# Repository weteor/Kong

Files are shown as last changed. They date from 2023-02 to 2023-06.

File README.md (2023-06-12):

### Kong

48 key orthogonal keyboard with offset bottom row

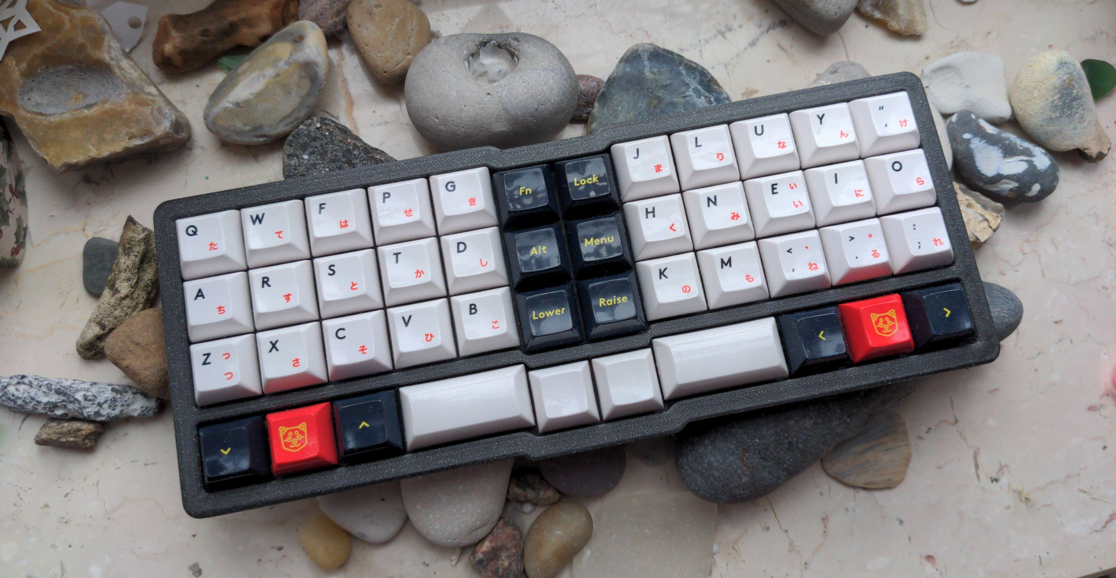
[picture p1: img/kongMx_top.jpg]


## Features

- seperate pcbs/cases for choc v1 and mx switches.
- Hotswap sockets
- onboard rp2040
- production files for pcba
- case files are supplied (stl, dxf, as well as the freecad files)
- QMK with vial support
- completely open source, permissive license ([CERN-OHL-P](https://cern-ohl.web.cern.ch/home))
- bottom rows supported:
  - 6x1u (MX)
  - 3x1u - 2u (MX and Choc)
  - 2x1u - 3u (MX)

## Want one?

All production files you need to build your own board can be found here: [choc](./prod/choc) / [mx](./prod/mx).

There are also production files with both pcbs combined to save on the assembly costs: [combined](./prod/combined)

## Case

#### Open bottom

The case is split in two parts connected by cylindrical 3mm diameter magnets. Two length are needed, 1.7mm and 3mm. The 3x3mm Magnets go into the shallow holes, so they poke out of the case. The 3x1.7mm magnets are pressed into the deeper holes. The longer magnet acting as a pin increasing stability and keeping the top part in place.

The bottom case is open by design and ends at a bit under the hotswap sockets. It's meant to be used with self adhesive neopren sheets (2-3mm thick), which are cut to be the same size as the pcb and then glued on top of the underside of the pcb.

#### Gasket mount

An alternative gasket mount case with a 4 degree tilt is also available for the MX version. 4mm x 3mm thick strips of foam is used to isolate the plate from PCB. Felt or other soft material similar in thickness can be used. M2 x 6mm flat head screws are used to fasten the case together.

#### Files

- [CAD files](./case)
- [stl (MX)](./prod/mx/case)
- [stl (choc)](./prod/choc/case)

## Parts

Parts needed beside the assembled pcbs:

- 48 hotswap sockets ( mx or choc)
- 48 of your favourite switches (mx or choc)
- (Choc only) 1x 1.6mm mid-mount 16-pin USB-C connector. I've omitted this from assembly to avoid needing the higher tier assembly. Those connectors can easily be found on Aliexpress, Mouse, Digikey etc. and are quite easy to handsolder

## Firmware
firmware configs for qmk and vial can be found in the respective firmware folders: [choc](./firmware/kong) / [mx](./firmware/kongmx).

The first time the pcb is plugged in, the bootloader will provide a drive to upload the firmware file.
You may either build the firmware yourself or use the provided vial firmware files [here](./firmware/uf2). You can use VIAL ([download](https://get.vial.today/) to program your board after that, without need to build a new firmware.

## The rest

Everything in this repository is free to use however you might see fit. If you want to support me and my projects, please consider linking back to this repository if you build/change/use anything.

If you would like to send me a tip, you could do it [here](https://ko-fi.com/weteor) (Please don't feel like you have to).

## More pictures

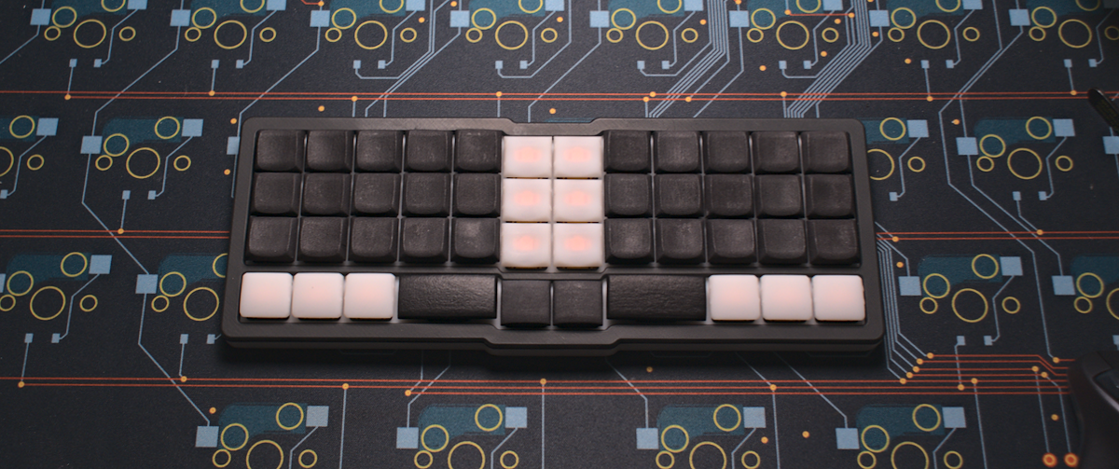
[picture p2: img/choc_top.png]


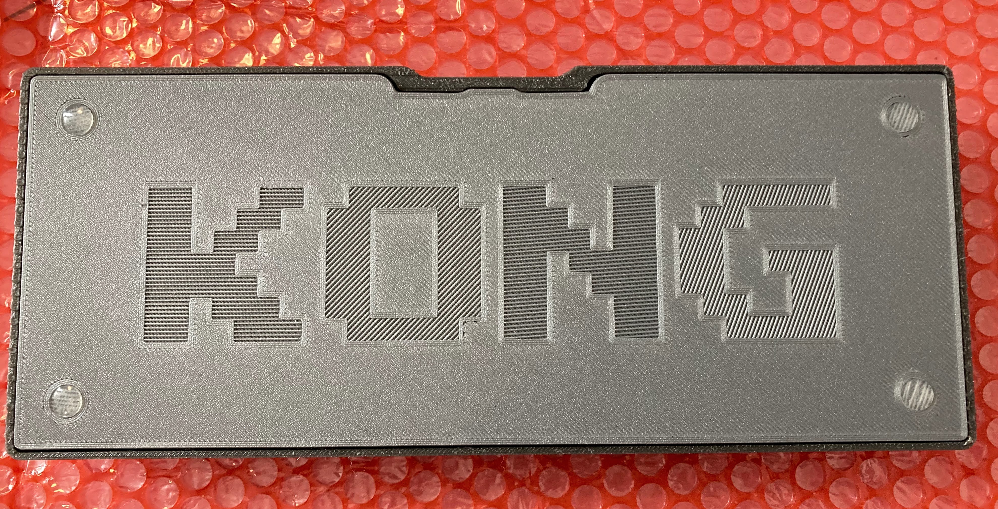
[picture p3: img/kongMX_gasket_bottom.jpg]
bottom


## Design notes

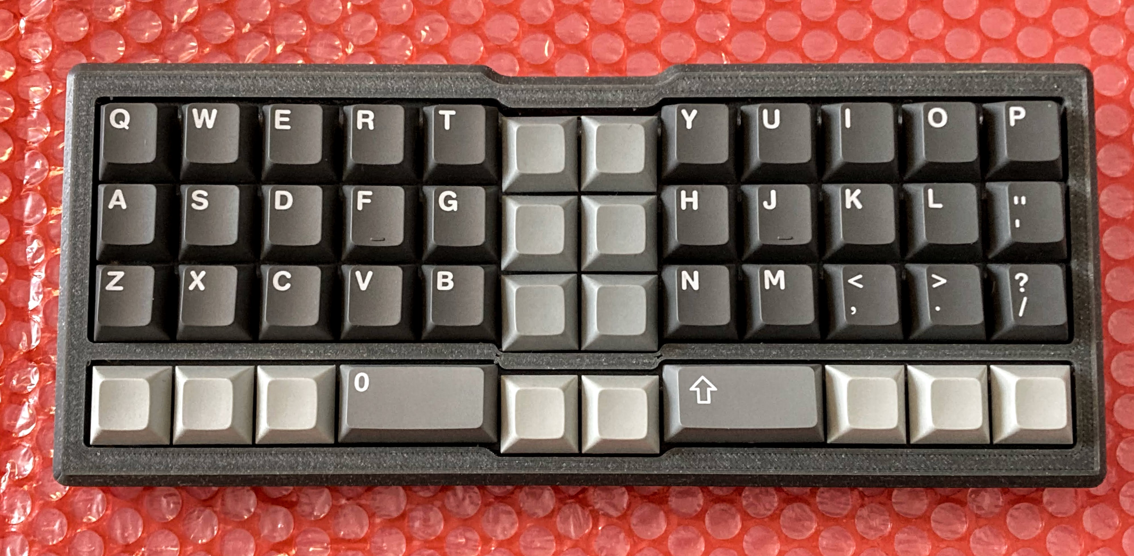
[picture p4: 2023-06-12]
img/kongMX_gasket_top.jpg

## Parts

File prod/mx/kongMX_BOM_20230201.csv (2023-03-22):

Comment | Designator | Footprint | LCSC
1uF | C500,C501,C503,C505 | Capacitor_SMD:C_0402_1005Metric | C52923
100nF | C502,C504,C506,C507,C508,C509,C512,C513 | Capacitor_SMD:C_0402_1005Metric | C1525
27pF | C510,C511 | Capacitor_SMD:C_0402_1005Metric | C1557
D | D500,D501,D502,D503,D504,D505,D506,D507,D508,D509,D510,D511,D512,D513,D514,D515,D516,D517,D518,D519,D520,D521,D522,D523,D524,D525,D526,D527,D528,D529,D530,D531,D532,D533,D534,D535,D536,D537,D538,D539,D540,D541,D542,D543,D544,D545,D546,D547 | weteor:D_SOD-123 | C81598
USB_C_Receptacle_USB2.0 | J500 | weteor:USB-C-31-M-12 | C165948
5.1k | R500,R501 | Resistor_SMD:R_0402_1005Metric | C25905
27R | R502,R503 | Resistor_SMD:R_0402_1005Metric | C100353
1k | R504,R505,R506 | Resistor_SMD:R_0402_1005Metric | C11702
10k | R507 | Resistor_SMD:R_0402_1005Metric | C25744
XC6206PxxxMR | U500 | Package_TO_SOT_SMD:SOT-23 | C5446
USBLC6-2SC6 | U501 | Package_TO_SOT_SMD:SOT-23-6 | C2827654
W25Q128JVS | U502 | Package_SO:SOIC-8_5.23x5.23mm_P1.27mm | C97521
RP2040 | U503 | RP2040_minimal:RP2040-QFN-56 | C2040
Crystal_GND24_Small | Y500 | Crystal:Crystal_SMD_2520-4Pin_2.5x2.0mm | C284156

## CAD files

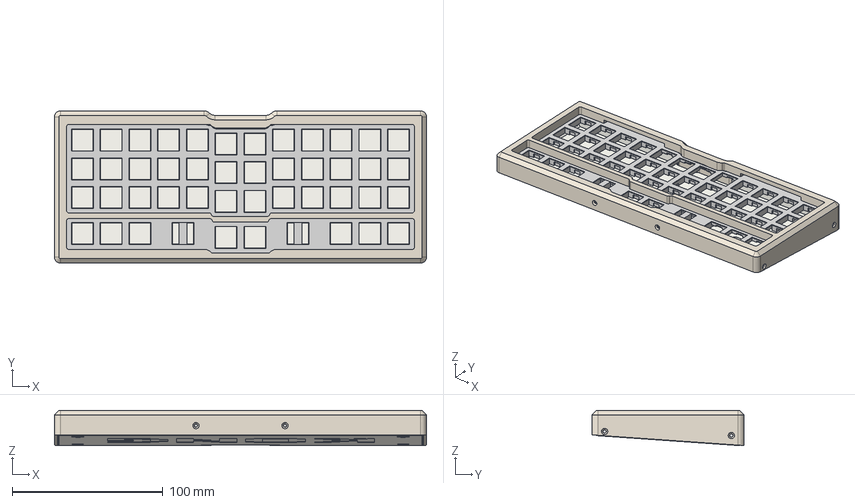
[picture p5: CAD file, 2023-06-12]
case/case_KongMX_gasket.step
246.6 x 101.0 x 23.4 mm
top
bottom
plate 1u
plate 2u

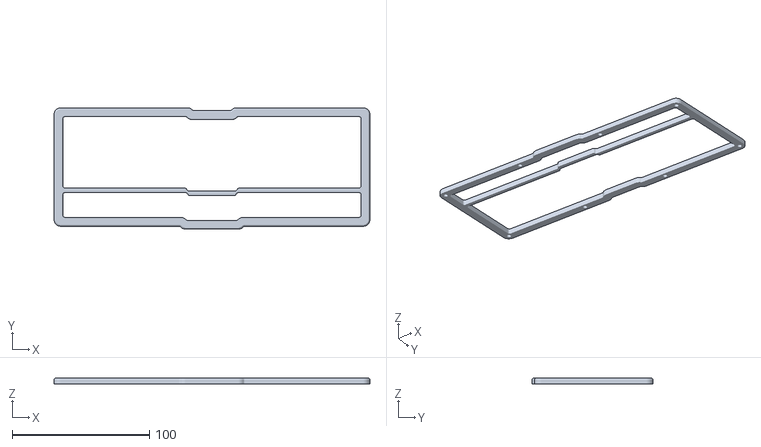
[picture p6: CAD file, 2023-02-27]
prod/choc/case/case_top.stl
230.0 x 88.4 x 4.50

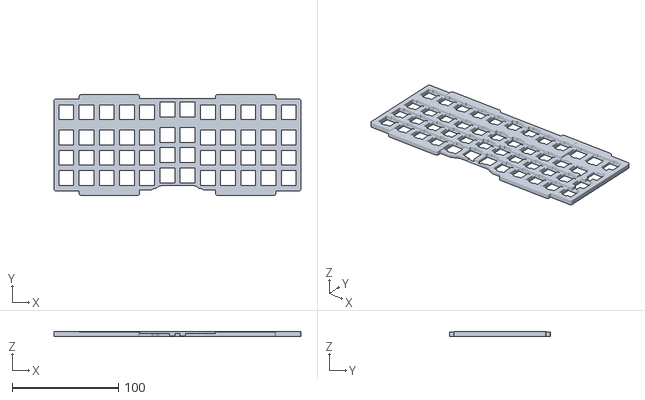
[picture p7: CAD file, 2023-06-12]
prod/mx/case/kongMX_gasket_plate_1u.stl
232.6 x 95.0 x 4.75

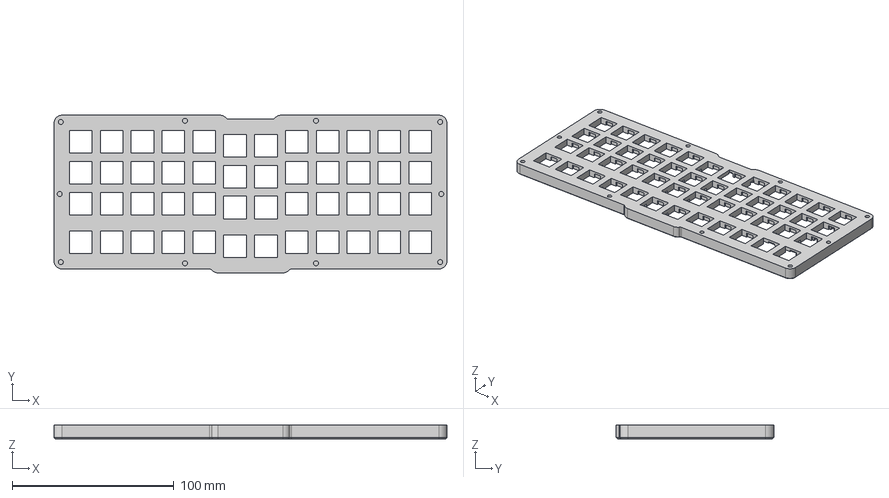
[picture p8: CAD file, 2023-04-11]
case/case_kongMX-Bottom-1u.step
242.6 x 97.3 x 8.35 mm

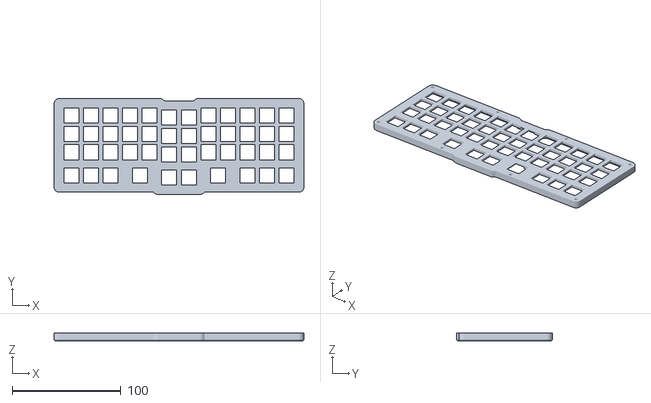
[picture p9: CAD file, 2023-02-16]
prod/choc/case/case_bottom.stl
230.0 x 88.4 x 7.05

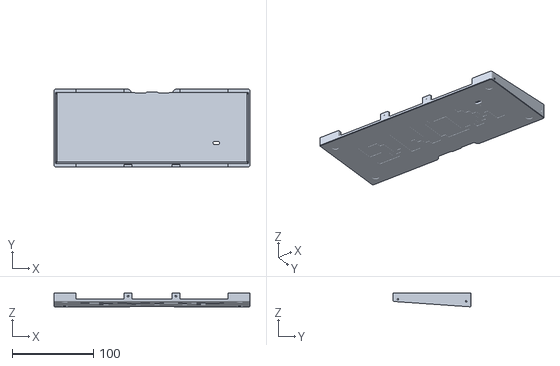
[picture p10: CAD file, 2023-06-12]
prod/mx/case/kongMX_gasket_bottom.stl
241.6 x 96.0 x 16.9

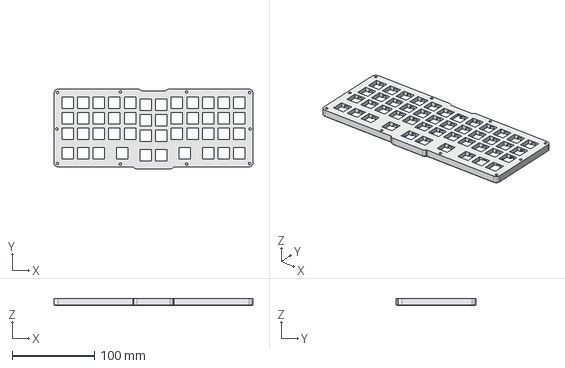
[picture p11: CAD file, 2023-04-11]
case/case_kongMX-Bottom.step
242.6 x 97.3 x 8.35 mm

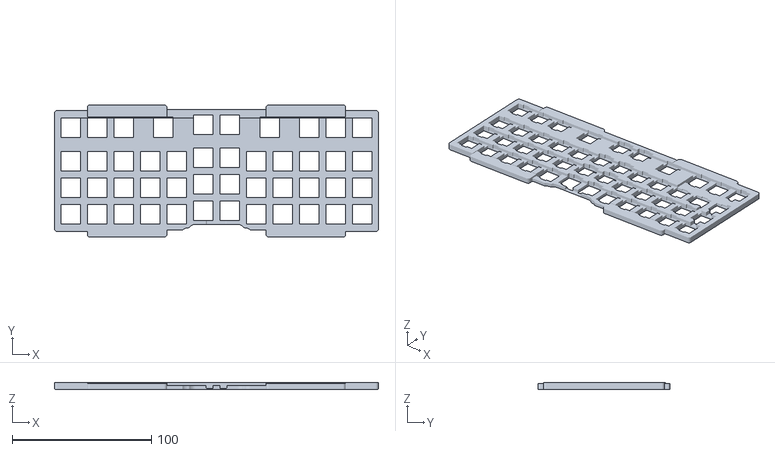
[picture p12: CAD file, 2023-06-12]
prod/mx/case/kongMX_gasket_plate_2x2u.stl
232.6 x 95.0 x 4.75

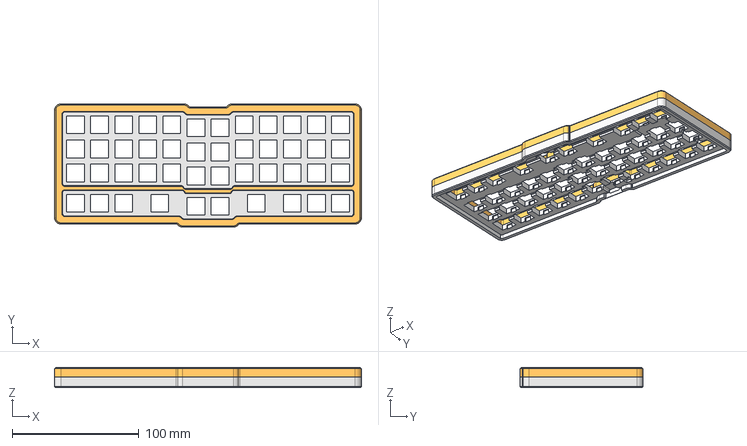
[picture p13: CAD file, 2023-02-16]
case/case_kongMX.FCStd
242.6 x 97.3 x 15.9 mm
Top
Bottom

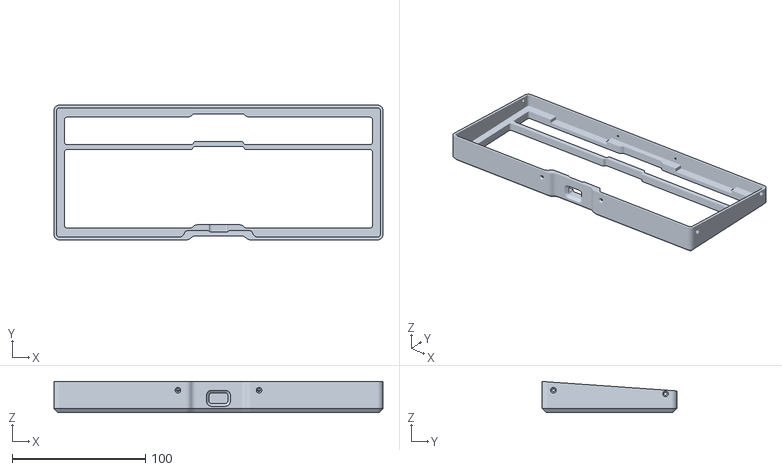
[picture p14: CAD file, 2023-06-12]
prod/mx/case/kongMX_gasket_top.stl
246.6 x 101.0 x 23.3

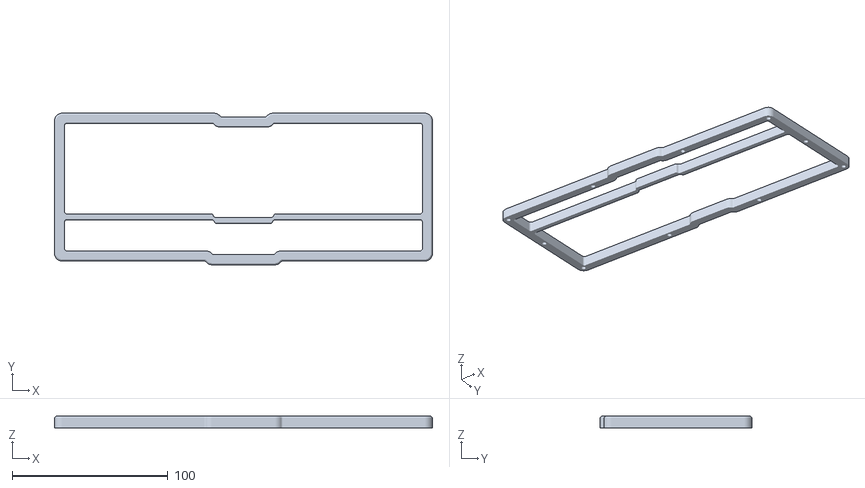
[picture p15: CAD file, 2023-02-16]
prod/mx/case/kongMX_top.stl
242.6 x 97.3 x 7.50

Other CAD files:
prod/mx/case/kongMX_bottom_1u.stl
prod/mx/case/kongMX_bottom.stl

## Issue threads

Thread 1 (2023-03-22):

Thumb key is off-centered in MX files

sporkus, 2023-03-22:
Hi Weteor,

Thanks for your wonderful designs. I am getting the Kong and Spc Evdr fabricated right now.

It looks like a 3u switch footprint for the Kong MX is off centered for all 1u or 3u configuration (the first 3u footprint left from center). I can see it in the MX and combined production gerber files, and the kicad files as well. It doesn't affect the 2u build like yours.

Current state/production gerbers:
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

Fixed:
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

I can make a PR for the fix if you'd like me to.

Thanks!

weteor, 2023-03-22:
Hi,

thanks a lot for noticing and letting me know, totally missed that.

I've fixed the issue and uploaded new files!

Hope you will enjoy those boards!

weteor, 2023-03-22:
Right. The footprint value in the BOM was incorrect, position file and LSCS number are correct.

Fixed that, shouldn't have been a problem though.

Just to be clear:
MX version uses surface mount  USB-C-31-M-12, which can be assembled without extra cost
Choc version uses mid mount USB-C-31-M-14, which I've taken out of the BOM, so it can be hand soldered.

Closed 2023-03-22.

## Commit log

2023-02-16 add pcb files
    [kongChoc.kicad_sch, kongMX.kicad_sch]
2023-02-16 add case files
    [case_kongMX.FCStd]
2023-02-16 add pcb production files
    [kongChoc_BOM_20230201.csv, kongChoc_POSITION_20230201.csv, kongMX_BOM_20230201.csv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]
2023-02-16 add case stls
    [case_bottom.stl, case_top.stl, kongMX_bottom.stl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]
2023-02-27 fix case for choc
2023-02-27 changed top case stl
    [case_top.stl]
2023-03-22 fix off-grid left 3u switch
    [kongChoc.kicad_sch]
2023-03-22 add fixed KongMX kicad pcb file
2023-03-23 adding 1u case
    [1u.step, case_kongMX-Bottom.step]
2023-03-23 rename for consistency
    [case_kongMX-Bottom-1u.step]
2023-03-23 add stl
    [kongMX_bottom_1u.stl]
2023-04-17 added a gasket mount case for MX
    [case_KongMX_gasket.step, kongMX_gasket_bottom.stl, kongMX_gasket_plate_1u.stl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]
